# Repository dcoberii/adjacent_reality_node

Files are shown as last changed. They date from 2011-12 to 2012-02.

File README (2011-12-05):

Copy 99-dfu_programmer.rules to /etc/udev/rules.d to use with non-root users

Status:
  avr_src/fusion_raw.c 			incomplete and untested (hardware unavailable)
  avr_src/twi.*				complete, may add features later
  avr_src/l3g4200d.* lsm3003dlm.*	simple but complete, may add features later
  avr_src/usb_hid.*			grotty but barely functional, will be replaced (priority)
  avr_src/Makefile			got a little overzealous with the dependencies

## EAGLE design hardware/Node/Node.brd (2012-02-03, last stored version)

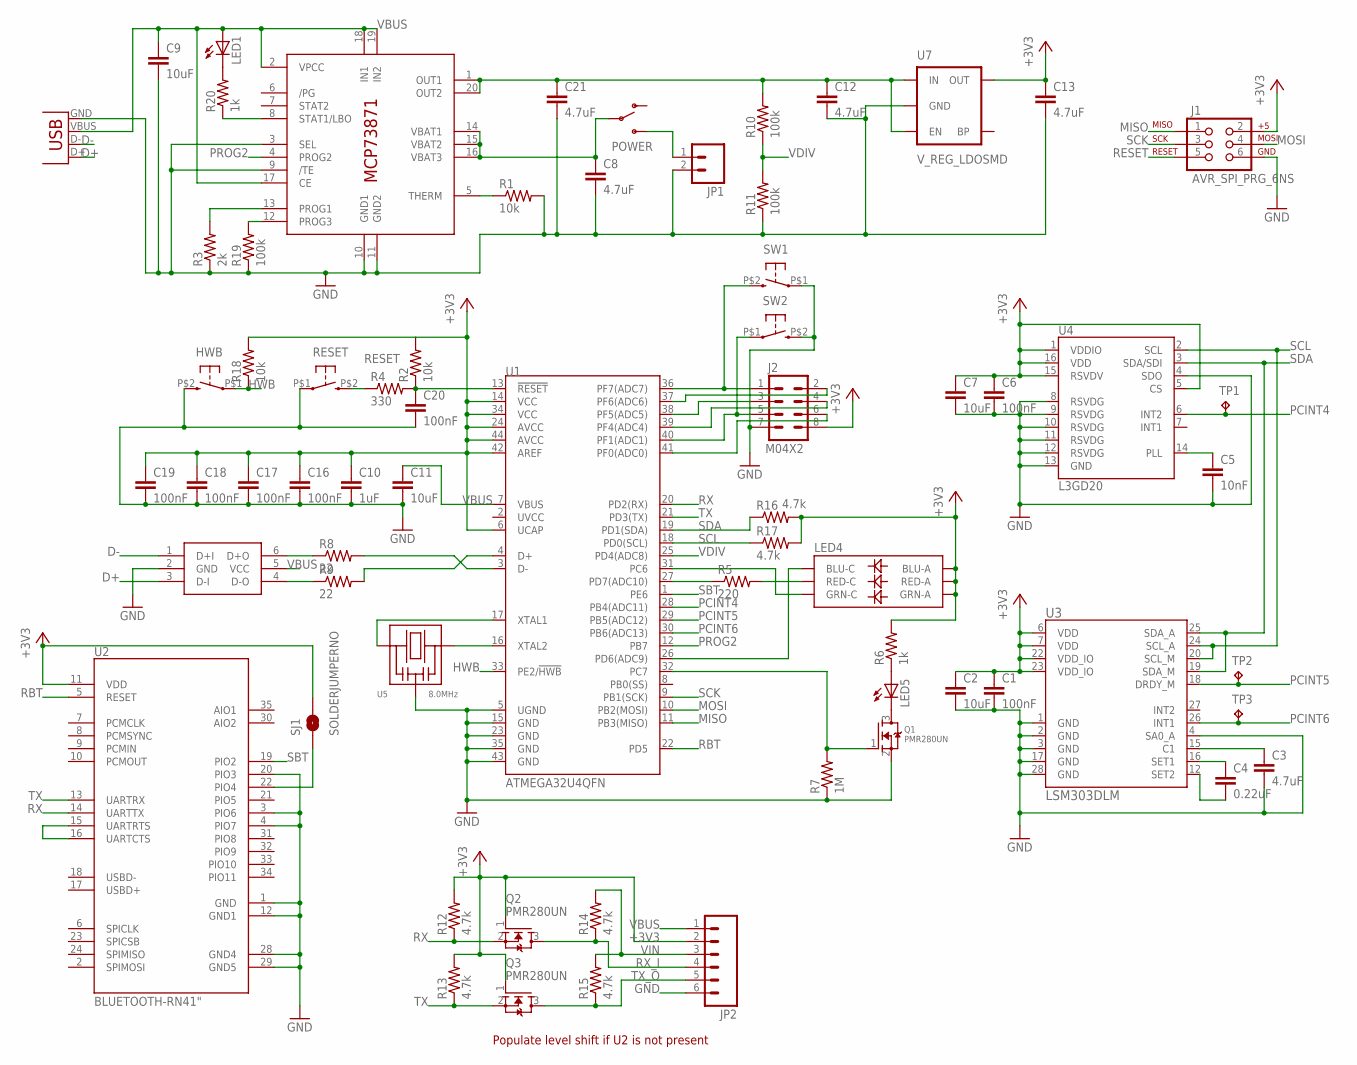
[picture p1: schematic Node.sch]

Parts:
C1, C6, C16, C17, C18, C19, C20: 100nF; 0402-CAP
C2, C7, C9, C11: 10uF; 0603-CAP
C3, C8, C12, C13, C21: 4.7uF; 0603-CAP
C4: 0.22uF; 0402-CAP
C5: 10nF; 0402-CAP
C10: 1uF; 0402-CAP
HWB: KSS
J1: AVR_SPI_PRG_6NS; 2X3-NS
J2: M04X2; 2X4
JP1: M02-JST-2MM-SMT; JST-2-SMD
JP2: M06SIP; 1X06
LED1, LED5: LED0603; LED-0603
LED4: LED-TRICOLOR-5050LED-TRICOLOR-0606; 0606
POWER: SWITCH-SPST-SMD-A
Q1, Q2, Q3: PMR280UN; SOT416
R1, R2, R18: 10k; 0402-RES
R3: 2k; 0402-RES
R4: 330; 0402-RES
R5: 220; 0402-RES
R6, R20: 1k; 0402-RES
R7: 1M; 0402-RES
R8, R9: 22; 0402-RES
R10, R11, R19: 100k; 0402-RES
R12, R13, R14, R15, R16, R17: 4.7k; 0402-RES
RESET: KSS
SJ1: SOLDERJUMPERNO; SJ_2S-NO
SW1, SW2: KSS
TP1, TP2, TP3: TPTP06R; TP06R
U1: ATMEGA32U4QFN; QFN-44
U2: BLUETOOTH-RN41"; RN41
U3: LSM303DLM; LGA28-5X5
U4: L3GD20; LGA16-4X4
U5: 8.0MHz; SMT_RESONATOR_3731
U6: MCP73871; QFN20
U7: V_REG_LDOSMD; SOT23-5
U9: RCLAMP0502A; SOT-666
X1: USBSMD; USB-MINIB

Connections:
+3V3: C1.1, C2.1, C6.1, C7.1, C10.1, C13.1, C16.1, C17.1, C18.1, C19.1, J1.2, J2.8, JP2.2, LED4.4 (BLU-A), LED4.5 (RED-A), LED4.6 (GRN-A), Q2.1 (G), Q3.1 (G), R2.2, R6.2, R12.2, R13.2, R16.2, R17.2, R18.2, SJ1.2, U1.6 (UCAP), U1.14 (VCC), U1.24 (AVCC), U1.34 (VCC), U1.42 (AREF), U1.44 (AVCC), U2.11 (VDD), U3.6 (VDD), U3.7 (VDD), U3.22 (VDD_IO), U3.23 (VDD_IO), U4.1 (VDDIO), U4.5 (CS), U4.15 (RSVDV), U4.16 (VDD), U7.5 (OUT)
D+: U9.3 (D-I), X1.D+
D-: U9.1 (D+I), X1.D-
GND: C1.2, C2.2, C3.2, C5.2, C6.2, C7.2, C8.2, C9.2, C10.2, C11.2, C12.2, C13.2, C16.2, C17.2, C18.2, C19.2, C20.2, C21.2, HWB.P$2 (3), J1.6, J2.7, JP1.2, JP2.6, Q1.2 (S), R1.2, R3.1, R7.1, R11.1, R19.1, RESET.P$1 (1), SW1.P$1 (1), SW2.P$2 (3), U1.5 (UGND), U1.15 (GND), U1.23 (GND), U1.35 (GND), U1.43 (GND), U2.1 (GND), U2.3 (PIO6), U2.4 (PIO7), U2.12 (GND1), U2.20 (PIO3), U2.28 (GND4), U2.29 (GND5), U3.1 (GND), U3.2 (GND), U3.3 (GND), U3.4 (SA0_A), U3.17 (GND), U3.28 (GND), U4.4 (SDO), U4.8 (RSVDG), U4.9 (RSVDG), U4.10 (RSVDG), U4.11 (RSVDG), U4.12 (RSVDG), U4.13 (GND), U5.P$2 (GND), U6.3 (SEL), U6.9 (/TE), U6.10 (GND1), U6.11 (GND2), U7.2 (GND), U9.2 (GND), X1.GND
HWB: HWB.P$1 (1), R18.1, U1.33 (PE2/!HWB)
MISO: J1.1, U1.11 (PB3(MISO))
MOSI: J1.4, U1.10 (PB2(MOSI))
unnamed: U1.16 (XTAL2), U5.P$3 (2)
unnamed: U1.17 (XTAL1), U5.P$1 (1)
unnamed: C3.1, U3.15 (C1)
unnamed: C8.1, POWER.2, U6.14 (VBAT1), U6.15 (VBAT2), U6.16 (VBAT3)
unnamed: C4.1, U3.16 (SET1)
unnamed: C4.2, U3.12 (SET2)
unnamed: C5.1, U4.14 (PLL)
unnamed: R1.1, U6.5 (THERM)
unnamed: U2.15 (UARTRTS), U2.16 (UARTCTS)
unnamed: LED4.2 (RED-C), R5.2
unnamed: C12.1, C21.1, R10.2, U6.1 (OUT1), U6.20 (OUT2), U7.1 (IN), U7.3 (EN)
unnamed: LED4.3 (GRN-C), U1.31 (PC6)
unnamed: LED1.C, R20.2
unnamed: SJ1.1, U2.22 (PIO4)
unnamed: R8.2, U1.3 (D-)
unnamed: R3.2, U6.13 (PROG1)
unnamed: LED4.1 (BLU-C), U1.26 (PD6(ADC9))
unnamed: R5.1, U1.27 (PD7(ADC10))
unnamed: R20.1, U6.8 (STAT1/LBO)
unnamed: LED5.C, Q1.3 (D)
unnamed: LED5.A, R6.1
unnamed: Q1.1 (G), R7.2, U1.32 (PC7)
unnamed: R9.2, U1.4 (D+)
unnamed: R8.1, U9.6 (D+O)
unnamed: R9.1, U9.4 (D-O)
unnamed: C20.1, R2.1, R4.2, U1.13 (!RESET)
unnamed: J2.1, SW1.P$2 (3), U1.36 (PF7(ADC7))
unnamed: JP1.1, POWER.3 (S)
unnamed: J2.2, U1.37 (PF6(ADC6))
unnamed: J2.3, U1.38 (PF5(ADC5))
unnamed: J2.4, U1.39 (PF4(ADC4))
unnamed: J2.5, SW2.P$1 (1), U1.40 (PF1(ADC1))
unnamed: J2.6, U1.41 (PF0(ADC0))
unnamed: R19.2, U6.12 (PROG3)
PCINT4: TP1.TP, U1.28 (PB4(ADC11)), U4.6 (INT2)
PCINT5: TP2.TP, U1.29 (PB5(ADC12)), U3.18 (DRDY_M)
PCINT6: TP3.TP, U1.30 (PB6(ADC13)), U3.26 (INT1)
PROG2: U1.12 (PB7), U6.4 (PROG2)
RBT: U1.22 (PD5), U2.5 (RESET)
RESET: J1.5, R4.1, RESET.P$2 (3)
RX: Q2.2 (S), R12.1, U1.20 (PD2(RX)), U2.14 (UARTTX)
RX_I: JP2.4, Q2.3 (D), R14.1
SBT: U1.1 (PE6), U2.19 (PIO2)
SCK: J1.3, U1.9 (PB1(SCK))
SCL: R17.1, U1.18 (PD0(SCL)), U3.20 (SCL_M), U3.24 (SCL_A), U4.2 (SCL)
SDA: R16.1, U1.19 (PD1(SDA)), U3.19 (SDA_M), U3.25 (SDA_A), U4.3 (SDA/SDI)
TX: Q3.2 (S), R13.1, U1.21 (PD3(TX)), U2.13 (UARTRX)
TX_O: JP2.5, Q3.3 (D), R15.1
VBUS: C9.1, C11.1, JP2.1, LED1.A, U1.7 (VBUS), U6.2 (VPCC), U6.17 (CE), U6.18 (IN1), U6.19 (IN2), U9.5 (VCC), X1.VBUS
VDIV: R10.1, R11.2, U1.25 (PD4(ADC8))
VIN: JP2.3, R14.2, R15.2

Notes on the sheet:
Populate level shift if U2 is not present

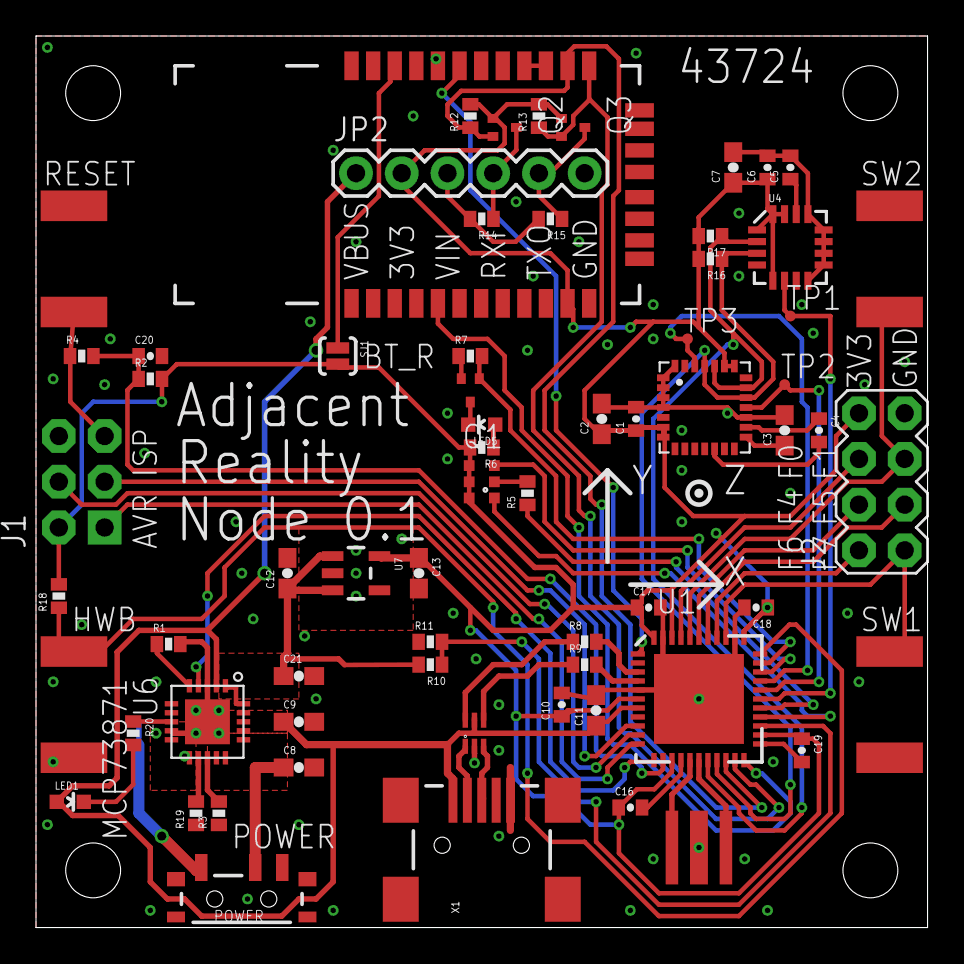
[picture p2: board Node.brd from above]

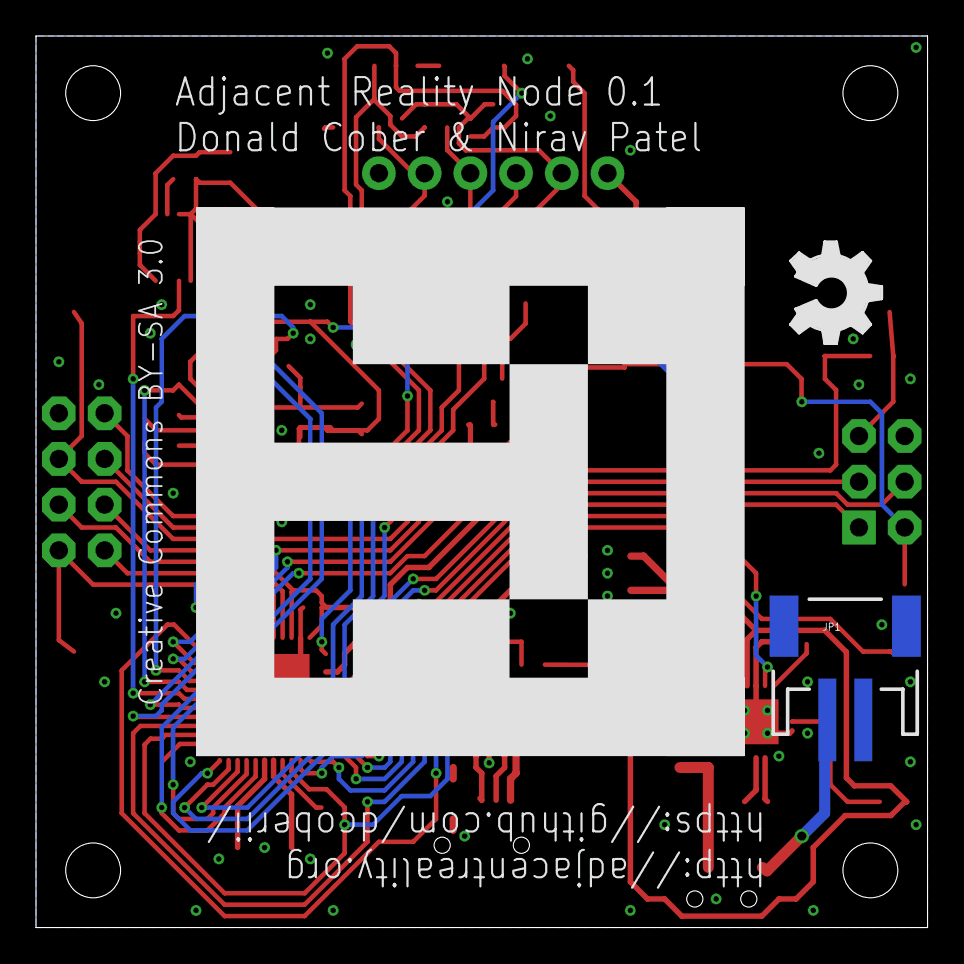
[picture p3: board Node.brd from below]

Board: 2 copper layers, 49.5 x 49.5 mm, 72 parts (2 on the bottom side), 58 nets.

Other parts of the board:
OSHW: OSHW_FILLX200_NOTEXT
U$1, U$2, U$3, U$4: STAND-OFF-TIGHT

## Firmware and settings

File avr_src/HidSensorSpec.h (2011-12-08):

///////////////////////////////////////////////////////////////////////////////////
//
// HidSensorSpec.h : Defines compliant with HID Sensor Spec.
//
// From Section 4.1 of Request 39
//
////////////////////////////////////////////////////////////////////////////////////


#ifndef _HIDSENSORSPEC_H_

#define _HIDSENSORSPEC_H_

#define HID_USAGE_PAGE_SENSOR											0x05,0x20

//sensor category usages
#define HID_USAGE_SENSOR_TYPE_COLLECTION								0x09,0x01

//sensor category biometric
#define HID_USAGE_SENSOR_CATEGORY_BIOMETRIC								0x09,0x10
#define HID_USAGE_SENSOR_TYPE_BIOMETRIC_PRESENCE						0x09,0x11
#define HID_USAGE_SENSOR_TYPE_BIOMETRIC_PROXIMITY						0x09,0x12
#define HID_USAGE_SENSOR_TYPE_BIOMETRIC_TOUCH							0x09,0x13

//sensor category electrical
#define HID_USAGE_SENSOR_CATEGORY_ELECTRICAL							0x09,0x20
#define HID_USAGE_SENSOR_TYPE_ELECTRICAL_CAPACITANCE					0x09,0x21
#define HID_USAGE_SENSOR_TYPE_ELECTRICAL_CURRENT						0x09,0x22
#define HID_USAGE_SENSOR_TYPE_ELECTRICAL_POWER							0x09,0x23
#define HID_USAGE_SENSOR_TYPE_ELECTRICAL_INDUCTANCE						0x09,0x24
#define HID_USAGE_SENSOR_TYPE_ELECTRICAL_RESISTANCE						0x09,0x25
#define HID_USAGE_SENSOR_TYPE_ELECTRICAL_VOLTAGE						0x09,0x26
#define HID_USAGE_SENSOR_TYPE_ELECTRICAL_POTENTIOMETER					0x09,0x27
#define HID_USAGE_SENSOR_TYPE_ELECTRICAL_FREQUENCY						0x09,0x28
#define HID_USAGE_SENSOR_TYPE_ELECTRICAL_PERIOD							0x09,0x29

//sensor category environmental
#define HID_USAGE_SENSOR_CATEGORY_ENVIRONMENTAL							0x09,0x30
#define HID_USAGE_SENSOR_TYPE_ENVIRONMENTAL_ATMOSPHERIC_PRESSURE		0x09,0x31
#define HID_USAGE_SENSOR_TYPE_ENVIRONMENTAL_HUMIDITY					0x09,0x32
#define HID_USAGE_SENSOR_TYPE_ENVIRONMENTAL_TEMPERATURE					0x09,0x33
#define HID_USAGE_SENSOR_TYPE_ENVIRONMENTAL_WIND_DIRECTION				0x09,0x34
#define HID_USAGE_SENSOR_TYPE_ENVIRONMENTAL_WIND_SPEED					0x09,0x35

//sensor category light
#define HID_USAGE_SENSOR_CATEGORY_LIGHT									0x09,0x40
#define HID_USAGE_SENSOR_TYPE_LIGHT_AMBIENTLIGHT						0x09,0x41
#define HID_USAGE_SENSOR_TYPE_LIGHT_CONSUMER_INFRARED					0x09,0x42

//sensor category location
#define HID_USAGE_SENSOR_CATEGORY_LOCATION								0x09,0x50
#define HID_USAGE_SENSOR_TYPE_LOCATION_BROADCAST						0x09,0x51
#define HID_USAGE_SENSOR_TYPE_LOCATION_DEAD_RECKONING					0x09,0x52
#define HID_USAGE_SENSOR_TYPE_LOCATION_GPS								0x09,0x53
#define HID_USAGE_SENSOR_TYPE_LOCATION_LOOKUP							0x09,0x54
#define HID_USAGE_SENSOR_TYPE_LOCATION_OTHER							0x09,0x55
#define HID_USAGE_SENSOR_TYPE_LOCATION_STATIC							0x09,0x56
#define HID_USAGE_SENSOR_TYPE_LOCATION_TRIANGULATION					0x09,0x57

//sensor category mechanical
#define HID_USAGE_SENSOR_CATEGORY_MECHANICAL							0x09,0x60
#define HID_USAGE_SENSOR_TYPE_MECHANICAL_BOOLEAN_SWITCH					0x09,0x61
#define HID_USAGE_SENSOR_TYPE_MECHANICAL_BOOLEAN_SWITCH_ARRAY			0x09,0x62
#define HID_USAGE_SENSOR_TYPE_MECHANICAL_MULTIVALUE_SWITCH				0x09,0x63
#define HID_USAGE_SENSOR_TYPE_MECHANICAL_FORCE							0x09,0x64
#define HID_USAGE_SENSOR_TYPE_MECHANICAL_PRESSURE						0x09,0x65
#define HID_USAGE_SENSOR_TYPE_MECHANICAL_STRAIN							0x09,0x66
#define HID_USAGE_SENSOR_TYPE_MECHANICAL_SCALE_WEIGHT					0x09,0x67
#define HID_USAGE_SENSOR_TYPE_MECHANICAL_VIBRATOR						0x09,0x68
#define HID_USAGE_SENSOR_TYPE_MECHANICAL_HALL_EFFECT_SWITCH				0x09,0x69

//sensor category motion
#define HID_USAGE_SENSOR_CATEGORY_MOTION								0x09,0x70
#define HID_USAGE_SENSOR_TYPE_MOTION_ACCELEROMETER_1D					0x09,0x71
#define HID_USAGE_SENSOR_TYPE_MOTION_ACCELEROMETER_2D					0x09,0x72
#define HID_USAGE_SENSOR_TYPE_MOTION_ACCELEROMETER_3D					0x09,0x73
#define HID_USAGE_SENSOR_TYPE_MOTION_GYROMETER_1D						0x09,0x74
#define HID_USAGE_SENSOR_TYPE_MOTION_GYROMETER_2D						0x09,0x75
#define HID_USAGE_SENSOR_TYPE_MOTION_GYROMETER_3D						0x09,0x76
#define HID_USAGE_SENSOR_TYPE_MOTION_MOTION_DETECTOR					0x09,0x77
#define HID_USAGE_SENSOR_TYPE_MOTION_SPEEDOMETER						0x09,0x78
#define HID_USAGE_SENSOR_TYPE_MOTION_ACCELEROMETER						0x09,0x79
#define HID_USAGE_SENSOR_TYPE_MOTION_GYROMETER							0x09,0x7A

//sensor category orientation
#define HID_USAGE_SENSOR_CATEGORY_ORIENTATION							0x09,0x80
#define HID_USAGE_SENSOR_TYPE_ORIENTATION_COMPASS_1D					0x09,0x81
#define HID_USAGE_SENSOR_TYPE_ORIENTATION_COMPASS_2D					0x09,0x82
#define HID_USAGE_SENSOR_TYPE_ORIENTATION_COMPASS_3D					0x09,0x83
#define HID_USAGE_SENSOR_TYPE_ORIENTATION_INCLINOMETER_1D				0x09,0x84
#define HID_USAGE_SENSOR_TYPE_ORIENTATION_INCLINOMETER_2D				0x09,0x85
#define HID_USAGE_SENSOR_TYPE_ORIENTATION_INCLINOMETER_3D				0x09,0x86
#define HID_USAGE_SENSOR_TYPE_ORIENTATION_DISTANCE_1D					0x09,0x87
#define HID_USAGE_SENSOR_TYPE_ORIENTATION_DISTANCE_2D					0x09,0x88
#define HID_USAGE_SENSOR_TYPE_ORIENTATION_DISTANCE_3D					0x09,0x89
#define HID_USAGE_SENSOR_TYPE_ORIENTATION_DEVICE_ORIENTATION			0x09,0x8A
#define HID_USAGE_SENSOR_TYPE_ORIENTATION_COMPASS						0x09,0x8B
#define HID_USAGE_SENSOR_TYPE_ORIENTATION_INCLINOMETER					0x09,0x8C
#define HID_USAGE_SENSOR_TYPE_ORIENTATION_DISTANCE						0x09,0x8D

//sensor category scanner
#define HID_USAGE_SENSOR_CATEGORY_SCANNER								0x09,0x90
#define HID_USAGE_SENSOR_TYPE_SCANNER_BARCODE							0x09,0x91
#define HID_USAGE_SENSOR_TYPE_SCANNER_RFID								0x09,0x92
#define HID_USAGE_SENSOR_TYPE_SCANNER_NFC								0x09,0x93

//sensor category time
#define HID_USAGE_SENSOR_CATEGORY_TIME									0x09,0xA0
#define HID_USAGE_SENSOR_TYPE_TIME_ALARM								0x09,0xA1
#define HID_USAGE_SENSOR_TYPE_TIME_RTC									0x09,0xA2

//sensor category other
#define HID_USAGE_SENSOR_CATEGORY_OTHER									0x09,0xE0
#define HID_USAGE_SENSOR_TYPE_OTHER_CUSTOM								0x09,0xE1
#define HID_USAGE_SENSOR_TYPE_OTHER_GENERIC								0x09,0xE2
#define HID_USAGE_SENSOR_TYPE_OTHER_GENERIC_ENUMERATOR					0x09,0xE3
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

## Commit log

2011-12-05 Adds the basic code to stream raw sensor values across some hid messages Not complete or functional
2011-12-08 Added header for hid sensors (from usb hid docu) no change in function
2011-12-29 a start on a schemetic for the Node
    [Node.sch]
2011-12-30 Changed from usb hid to usb cdc acm By disabling the line coding options and handling the RX in an endpoint interrupt, these things actually look fairly similar
    Firmware is functional enough to collect raw data for offline fusion testing
2012-01-10 Complete alpha revision schematic
    [Node.sch]
2012-01-10 Added nfet style level shift Moved switch to other side of MAX1704x Changed C1 value from 100uF to 100nF Changed U1 symbol from NPN to NFET Added optional pullups on SDA/SCL Pullup on HWB Changed res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
    [Node.sch]
2012-01-21 use mcp73871 and cleanup
    [Node.sch]
2012-01-22 start of board layout
    [Node.brd]
2012-01-22 switched mosfets
    [Node.sch]
2012-01-22 put vbus on the header
    [Node.brd, Node.sch]
2012-01-26 Start of laying out traces
    [Node.brd]
2012-01-27 Routing more of the easy traces
    [Node.brd]
2012-01-28 route more of the breakouts
    [Node.brd, Node.sch]
2012-01-29 reorder some pins
    [Node.brd, Node.sch]
2012-01-29 route low battery led
    [Node.brd, Node.sch]
2012-01-30 move stuff to meet the DRC
    [Node.brd, Node.sch]
2012-01-30 fix packages, route ISP
    [Node.brd, Node.sch]
2012-01-31 route LEDs and interrupts
    [Node.brd, Node.sch]
2012-01-31 lay ground pours
    [Node.brd]
2012-01-31 moved a trace to make the bottom fully connected
    [Node.brd]
2012-02-01 expand keepout to board edge, fix ground pours
    [Node.brd, Node.sch]
2012-02-01 added vias, 1 airwire left!!!
    [Node.brd]
2012-02-01 Ratsnest: Nothing to do!
    [Node.brd]
2012-02-02 Add labels
    [Node.brd]
2012-02-03 make the fiducial aruco compatible
    [Node.brd]
2012-02-03 add Seeed order number to silkscreen
    [Node.brd]
2012-02-13 split the hardware into a new repo at https://github.com/AdjacentReality/NodeHardware
    [Node.brd, Node.sch]

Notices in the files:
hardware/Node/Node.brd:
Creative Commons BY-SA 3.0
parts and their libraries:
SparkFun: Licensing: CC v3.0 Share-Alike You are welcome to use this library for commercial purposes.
